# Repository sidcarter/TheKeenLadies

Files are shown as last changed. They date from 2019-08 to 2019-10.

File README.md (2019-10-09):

# Acheron TKL-SM-S-ATM32U4-MX-TH-WI (Codename "TheKeenLadies")

Acheron Logo

See [this page](https://gondolindrim.github.io/AcheronDocs/keenladies/intro.html) for the TheKeenLadies documentation.

## Supported layouts

Click [this link](http://www.keyboard-layout-editor.com/#/gists/6fcb43072b2efaa6a5129e3db566da86) for the KLE file for the TheKeenLadies PCB.

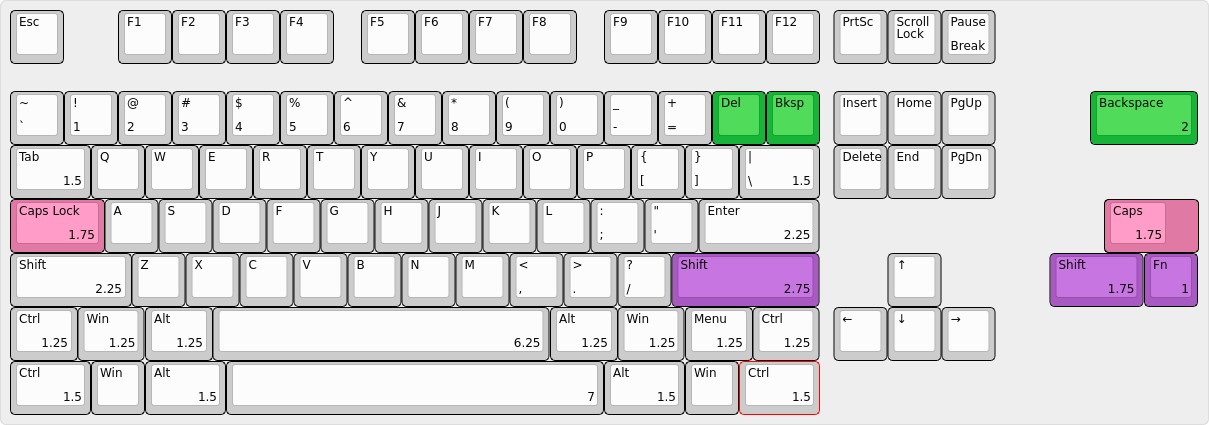
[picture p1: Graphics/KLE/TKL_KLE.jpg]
TKL layouts


## Renders

Click at the images to zoom in.

Renders generated by the [tracespace.io](https://tracespace.io/view/) site.

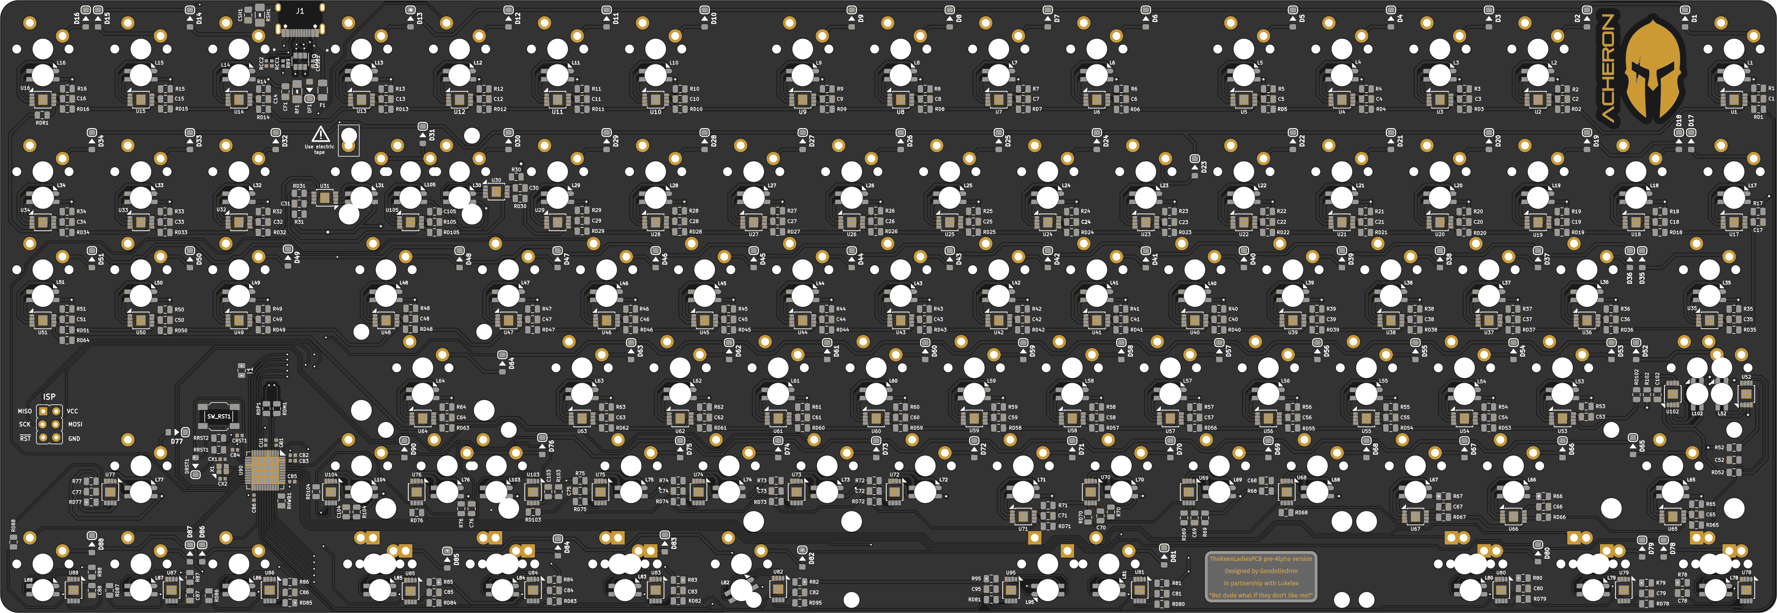
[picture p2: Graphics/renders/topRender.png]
TKL Top Render


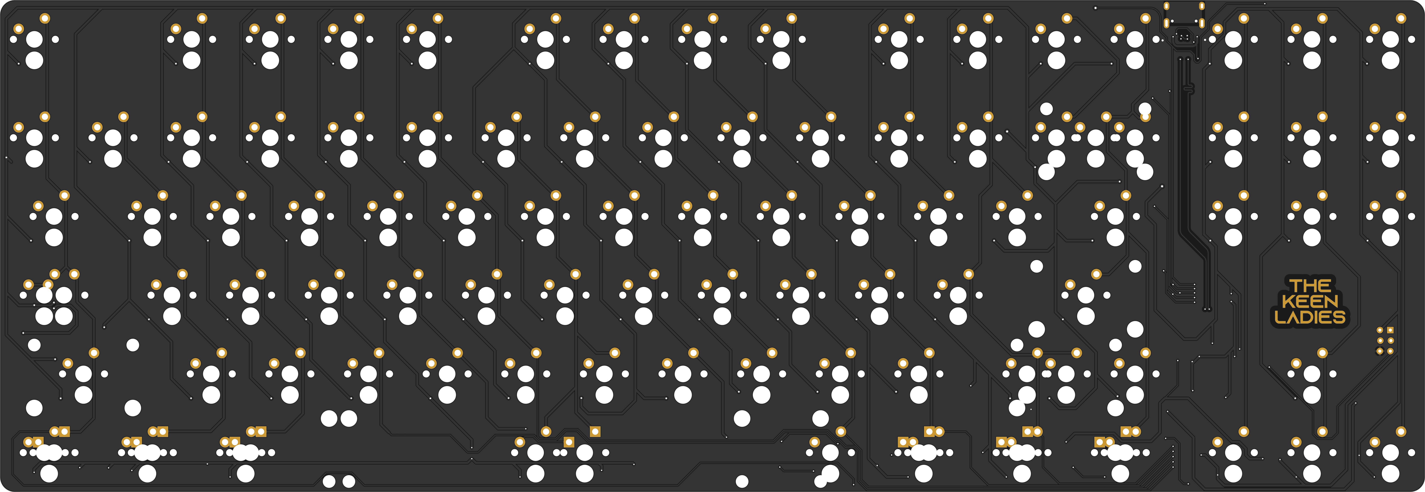
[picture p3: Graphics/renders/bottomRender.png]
TKL Bottom Render


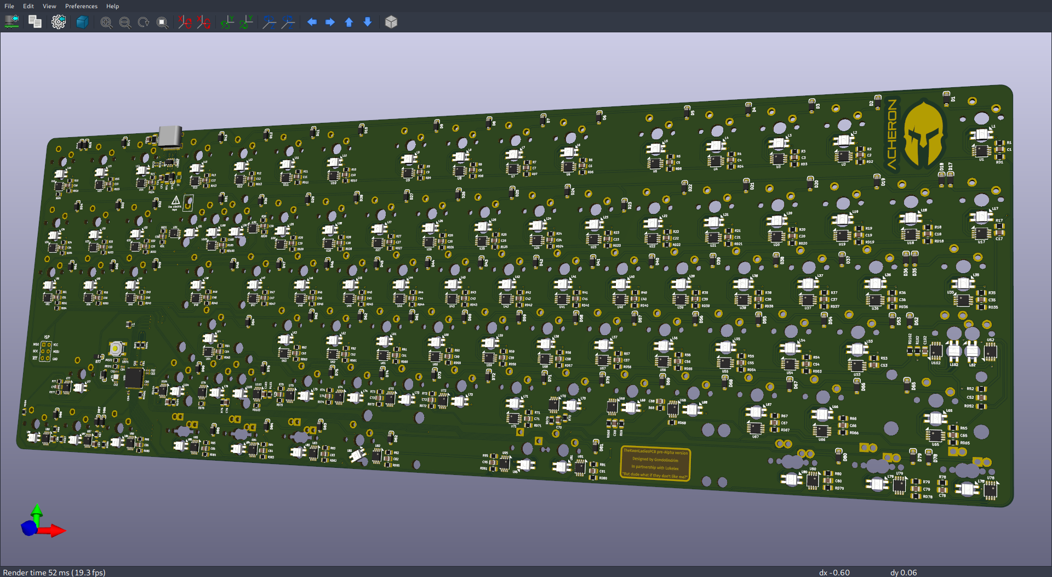
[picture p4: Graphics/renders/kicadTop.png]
TKL KiCad Top Render


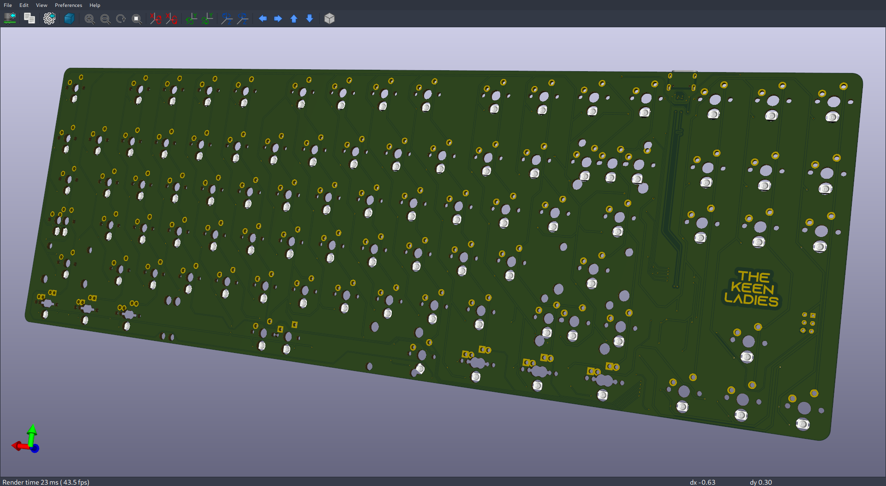
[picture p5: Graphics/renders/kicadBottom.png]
TKL KiCad Bottom Render


## Copyright notice

This project is released under the Acheron Open-Hardware License V1.1. For the license, please refer to the LICENCE.md file.

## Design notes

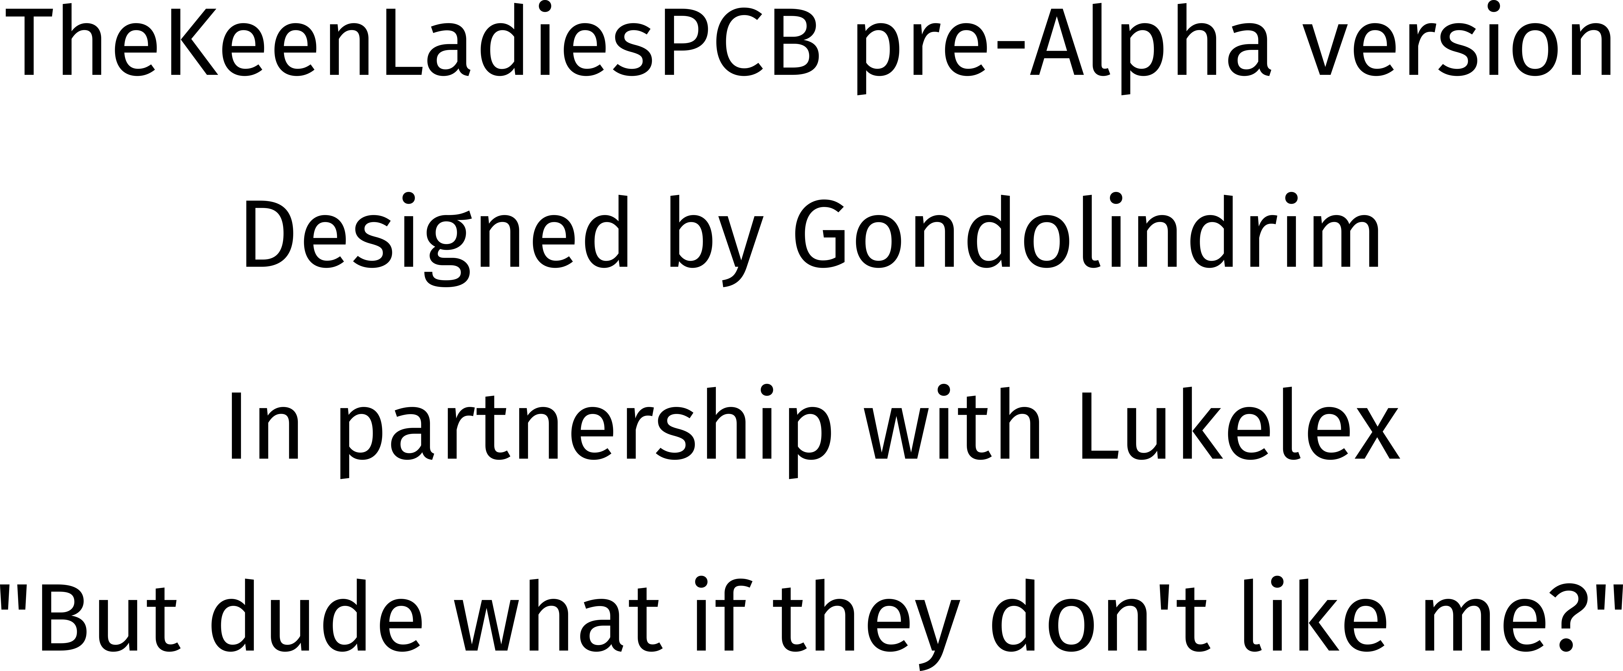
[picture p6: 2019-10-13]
Graphics/label/TKL_label.png

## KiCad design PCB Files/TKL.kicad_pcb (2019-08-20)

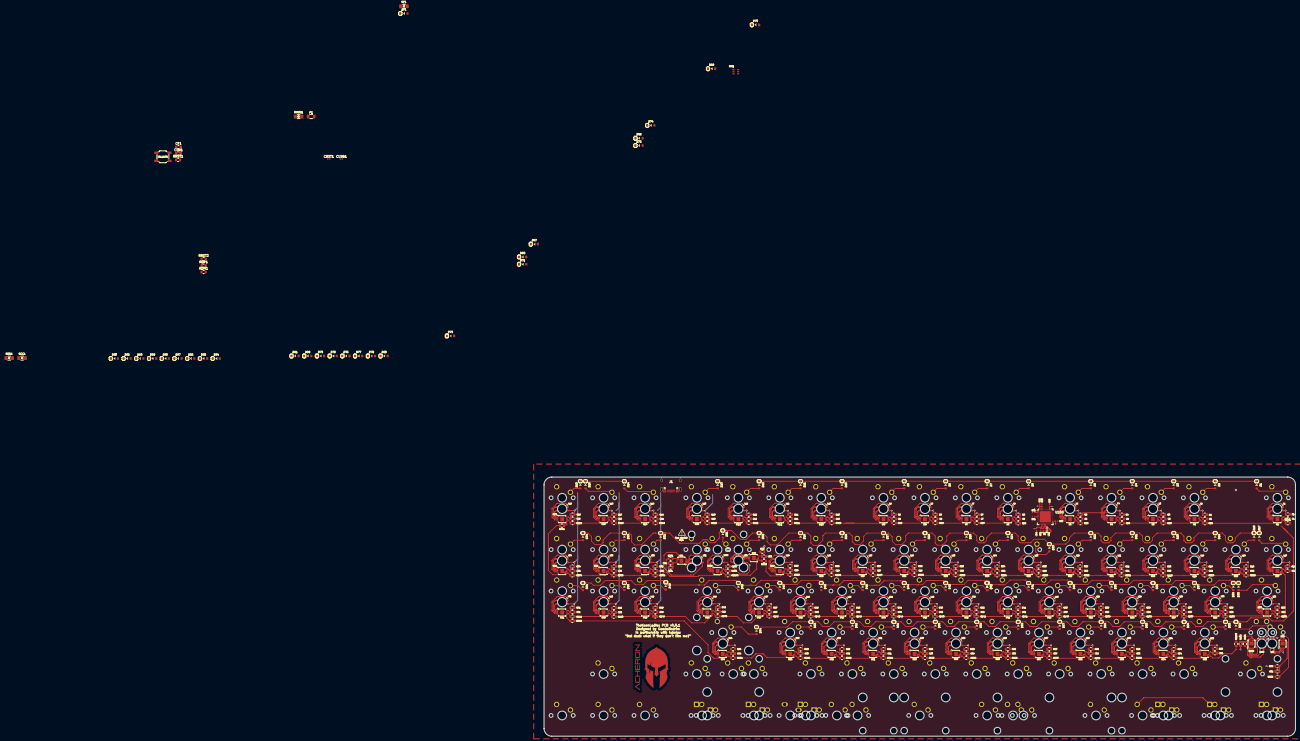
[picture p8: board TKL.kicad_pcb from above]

Board: 2 copper layers, 345.3 x 119.1 mm, 557 parts (1 on the bottom side), 527 nets.

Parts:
C1, C2, C3, C4, C5, C6, C7, C8, C9, C10, C11, C12, C13, C14, C15, C16, C17, C18, C19, C20, C21, C22, C23, C24, C25, C26, C27, C28, C29, C30, C31, C32, C33, C34, C35, C36, C37, C38, C39, C40, C41, C42, C43, C44, C45, C46, C47, C48, C49, C50, C51, C52, C53, C54, C55, C56, C57, C58, C59, C60, C61, C62, C63, C64, C102, C105: 100nF; C_0805_2012Metric
CB1: 1uF; C_0402_1005Metric
CB2, CB3, CB4, CB5, CB6: 100nF; C_0402_1005Metric
CF1: 1u; C_0805_2012Metric_Pad1.15x1.40mm_HandSolder
CRST1: 100nF; C_0402_1005Metric
CSH1: 100nF; C_0805_2012Metric_Pad1.15x1.40mm_HandSolder
CU1: 1uF; C_0402_1005Metric
CUSB1: 100nF; C_0402_1005Metric
CX1, CX2: 8.2pF; C_0402_1005Metric
D1, D2, D3, D4, D5, D6, D7, D8, D9, D10, D11, D12, D13, D14, D15, D16, D17, D18, D19, D20, D21, D22, D23, D24, D25, D26, D27, D28, D29, D30, D31, D32, D33, D34, D35, D36, D37, D38, D39, D40, D41, D42, D42#2, D43, D44, D45, D46, D47, D48, D49, D50, D51, D52, D53, D54, D55, D56, D57, D58, D59, D60, D61, D62, D63, D64, D65, D66, D67, D68, D69, D70, D71, D72, D73, D74, D75, D76, D77, D78, D79, D80, D81, D82, D83, D84, D85, D86, D87, D88, D89, D90: 1N4148; D_SOD-123
DF1: RB060M-60TR; D_SOD-123
F1: Polyfuse; Fuse_1206_3216Metric
G1: TKL Logo; TKL_Logo_11x18mm_Plated
G2: Acheron Short Logo Plated; acheronShort_15.2x21mm_Plated
G3: Warning sign; warning_sign_3.6x3.2mm
J1: USB_C; TYPE-C-31-M-12
L1, L2, L3, L4, L5, L6, L7, L8, L9, L10, L11, L12, L13, L14, L15, L16, L17, L18, L19, L20, L21, L22, L23, L24, L25, L26, L27, L28, L29, L30, L31, L32, L33, L34, L35, L36, L37, L38, L39, L40, L41, L42, L43, L44, L45, L46, L47, L48, L49, L50, L51, L52, L53, L54, L55, L56, L57, L58, L59, L60, L61, L62, L63, L64, L102, L105: LED_BGRA; LED_RGB_SMD_6028_2.8x3.5mm_Round
R1, R2, R3, R4, R5, R6, R7, R8, R9, R10, R11, R12, R13, R14, R15, R16, R17, R18, R19, R20, R21, R22, R23, R24, R25, R26, R27, R28, R29, R30, R31, R32, R33, R34, R35, R36, R37, R38, R39, R40, R41, R42, R43, R44, R45, R46, R47, R48, R49, R50, R51, R52, R53, R54, R55, R56, R57, R58, R59, R60, R61, R62, R63, R64, R102, R105: 100R; R_0805_2012Metric
RCC1: 5.1k; R_SMD_1026
RD1, RD2, RD3, RD4, RD5, RD6, RD7, RD8, RD9, RD10, RD11, RD12, RD13, RD14, RD15, RD16, RD18, RD19, RD20, RD21, RD22, RD23, RD24, RD25, RD26, RD27, RD28, RD29, RD30, RD31, RD32, RD33, RD34, RD35, RD36, RD37, RD38, RD39, RD40, RD41, RD42, RD43, RD44, RD45, RD46, RD47, RD48, RD49, RD50, RD51, RD52, RD54, RD55, RD56, RD57, RD58, RD59, RD60, RD61, RD62, RD63, RD64, RD102, RD105: 33R; R_0805_2012Metric
RDM1: 22; R_0805_2012Metric
RDP1: 22; R_0805_2012Metric
RDR1, RDR2: 33R; R_0805_2012Metric
RF1: 10k; R_SMD_1026
RHWB1: 1k; R_SMD_1026
RRST1: 4.7k; R_0805_2012Metric
RRST2: 330R; R_0805_2012Metric
RSH1: 1M; R_SMD_1026
SW1: ESC; MX100
SW2: F1; MX100
SW3: F2; MX100
SW4: F3; MX100
SW5: F4; MX100
SW6: F5; MX100
SW7: F6; MX100
SW8: F7; MX100
SW9: F8; MX100
SW10: F9; MX100
SW11: F10; MX100
SW12: F11; MX100
SW13: F12; MX100
SW14: PRTSC; MX100
SW15: SCRLCK; MX100
SW16: PAUSE; MX100
SW17: GRV; MX100
SW18: 1; MX100
SW19: 2; MX100
SW20: 3; MX100
SW21: 4; MX100
SW22: 5; MX100
SW23: 6; MX100
SW24: 7; MX100
SW25: 8; MX100
SW26: 9; MX100
SW27: 0; MX100
SW28: HIFEN; MX100
SW29: PLUS; MX100
SW30: BCKSLSH; MX100
SW31, SW49: DEL; MX100
SW32: INS; MX100
SW33: HOME; MX100
SW34: PGUP; MX100
SW35: TAB; MX150
SW36: Q; MX100
SW37: W; MX100
SW38: E; MX100
SW39: R; MX100
SW40: T; MX100
SW41: Y; MX100
SW42: U; MX100
SW43: I; MX100
SW44: O; MX100
SW45: P; MX100
SW46: LBRACES; MX100
SW47: RBRACES; MX100
SW48: BKSP_150; MX150
SW50: END; MX100
SW51: PGDN; MX100
SW52: CAPS; MX175
SW53: A; MX100
SW54: S; MX100
SW55: D; MX100
SW56: F; MX100
SW57: G; MX100
SW58: H; MX100
SW59: J; MX100
SW60: K; MX100
SW61: L; MX100
SW62: :; MX100
SW63: QUOTE; MX100
SW64: ENTER; MX225
SW65: LSHFT; MX225
SW66: Z; MX100
SW67: X; MX100
SW68: C; MX100
SW69: V; MX100
SW70: B; MX100
SW71: N; MX100
SW72: M; MX100
SW73: <,; MX100
SW74: .>; MX100
SW75: /; MX100
SW76: RSHFT_275; MX275
SW77: UP; MX100
SW78: LCTRL_B1; MX125
SW79: LGUI_B1; MX125
SW80: LALT_B1; MX125
SW81: SPACE_B1; MX625R
SW82: RALT_B1; MX125
SW83: RGUI_B1; MX125
SW84: MENU_R1; MX125
SW85: RCTRL_R1; MX125
SW86: LEFT; MX100
SW87: DOWN; MX100
SW88: RIGHT; MX100
SW89: LCTRL_B2; MX150
SW90: LGUI_B2; MX100
SW91: LALT_B3; MX100
SW92: LALT_B2; MX150
SW93: LGUI_B3; MX125
SW94: LSPC_R3; MX225R
SW95: SPACE_B2; MX700R
SW96: RSPC_B3; MX275R
SW97: RGUI_R3; MX125
SW98: RALT_B2; MX150
SW99: RALT_R3; MX100
SW100: RGUI_R2; MX100
SW101: RCTRL_R2; MX150
SW102: STEPPED_CAPS; MX125
SW103: RSHFT_175; MX175
SW104: Fn; MX100
SW105: BKSP_2U; MX200
SW_RST1: SW_Push; smdPushBtn
U1, U2, U3, U4, U5, U6, U7, U8, U9, U10, U11, U12, U13, U14, U15, U16, U17, U18, U19, U20, U21, U22, U23, U24, U25, U26, U27, U28, U29, U30, U31, U32, U33, U34, U35, U36, U37, U38, U39, U40, U41, U42, U43, U44, U45, U46, U47, U48, U49, U50, U51, U52, U53, U54, U55, U56, U57, U58, U59, U60, U61, U62, U63, U64, U102, U105: WS2811M; MSOP-8-1EP_3x3mm_P0.65mm_EP1.68x1.88mm
U200: ATMEGA32U4; QFN-44-1EP_7x7mm_P0.5mm_EP5.2x5.2mm
U201: USBLC6-2SC6; SOT-23-6
X1: 16MHz; Crystal_SMD_2016-4Pin_2.0x1.6mm

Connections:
5V: CB1.2, CB2.1, CB3.2, CB4.2, CB5.1, CB6.1, CF1.2, DF1.1, F1.1, L1.4, L2.4, L3.4, L4.4, L5.4, L6.4, L7.4, L8.4, L9.4, L10.4, L11.4, L12.4, L13.4, L14.4, L15.4, L16.4, L17.4, L18.4, L19.4, L20.4, L21.4, L22.4, L23.4, L24.4, L25.4, L26.4, L27.4, L28.4, L29.4, L30.4, L31.4, L32.4, L33.4, L34.4, L35.4, L36.4, L37.4, L38.4, L39.4, L40.4, L41.4, L42.4, L43.4, L44.4, L45.4, L46.4, L47.4, L48.4, L49.4, L50.4, L51.4, L52.4, L53.4, L54.4, L55.4, L56.4, L57.4, L58.4, L59.4, L60.4, L61.4, L62.4, L63.4, L64.4, L102.4, L105.4, R1.1, R2.1, R3.1, R4.1, R5.1, R6.1, R7.1, R8.1, R9.1, R10.1, R11.1, R12.1, R13.1, R14.1, R15.1, R16.1, R17.1, R18.1, R19.1, R20.1, R21.1, R22.1, R23.1, R24.1, R25.1, R26.1, R27.1, R28.1, R29.1, R30.1, R31.1, R32.1, R33.1, R34.1, R35.1, R36.1, R37.1, R38.1, R39.1, R40.1, R41.1, R42.1, R43.1, R44.1, R45.1, R46.1, R47.1, R48.1, R49.1, R50.1, R51.1, R52.1, R53.1, R54.1, R55.1, R56.1, R57.1, R58.1, R59.1, R60.1, R61.1, R62.1, R63.1, R64.1, R102.1, R105.1, RF1.2, RRST1.2, U200.2, U200.7, U200.14, U200.24, U200.35, U200.42, U200.44
/RST: CRST1.2, RRST1.1, RRST2.2, U200.13
/SHIELD: CSH1.1, J1.S, RSH1.2
/XTAL1: CX2.1, U200.17, X1.1
/XTAL2: CX1.1, U200.16, X1.3
Col1: SW1.1, SW17.1, SW35.1, SW52.1, SW65.1, SW78.1, SW89.1, SW102.1
Col2: SW18.1, SW36.1, SW53.1, SW66.1, SW79.1, SW90.1, SW91.1
Col3: SW2.1, SW19.1, SW37.1, SW54.1, SW67.1, SW80.1, SW92.1, SW93.1
Col4: SW3.1, SW20.1, SW38.1, SW55.1, SW68.1
Col5: SW4.1, SW21.1, SW39.1, SW56.1, SW69.1, SW94.1
Col6: SW5.1, SW22.1, SW40.1, SW57.1, SW70.1
Col7: SW23.1, SW41.1, SW58.1, SW71.1, SW81.1, SW95.1, SW96.1
Col8: SW6.1, SW24.1, SW42.1, SW59.1, SW72.1
Col9: SW7.1, SW25.1, SW43.1, SW60.1, SW73.1
Col10: SW8.1, SW26.1, SW44.1, SW61.1, SW74.1, SW82.1, SW97.1
Col11: SW9.1, SW27.1, SW45.1, SW62.1, SW75.1, SW83.1, SW98.1, SW99.1
Col12: SW10.1, SW28.1, SW46.1
Col13: SW11.1, SW29.1, SW47.1, SW63.1, SW76.1, SW84.1, SW100.1, SW103.1
Col14: SW12.1, SW30.1
Col15: SW13.1, SW31.1, SW48.1, SW64.1, SW85.1, SW101.1, SW104.1, SW105.1
Col16: SW14.1, SW32.1, SW49.1, SW86.1
Col17: SW15.1, SW33.1, SW50.1, SW77.1, SW87.1
Col18: SW16.1, SW34.1, SW51.1, SW88.1
DBusN: J1.A7, J1.B7, U201.1
DBusP: J1.A6, J1.B6, U201.3
DN: RDM1.2, U200.3
DP: RDP1.1, U200.4
GND: C1.2, C2.2, C3.2, C4.2, C5.2, C6.2, C7.2, C8.2, C9.2, C10.2, C11.2, C12.2, C13.2, C14.2, C15.2, C16.2, C17.2, C18.2, C19.2, C20.2, C21.2, C22.2, C23.2, C24.2, C25.2, C26.2, C27.2, C28.2, C29.2, C30.2, C31.2, C32.2, C33.2, C34.2, C35.2, C36.2, C37.2, C38.2, C39.2, C40.2, C41.2, C42.2, C43.2, C44.2, C45.2, C46.2, C47.2, C48.2, C49.2, C50.2, C51.2, C52.2, C53.2, C54.2, C55.2, C56.2, C57.2, C58.2, C59.2, C60.2, C61.2, C62.2, C63.2, C64.2, C102.2, C105.2, CB1.1, CB2.2, CB3.1, CB4.1, CB5.2, CB6.2, CF1.1, CRST1.1, CSH1.2, CU1.2, CUSB1.2, CX1.2, CX2.2, DF1.2, J1.A1, J1.B1, RCC1.2, RF1.1, RHWB1.1, RSH1.1, SW_RST1.1, U1.4, U1.9, U2.4, U2.9, U3.4, U3.9, U4.4, U4.9, U5.4, U5.9, U6.4, U6.9, U7.4, U7.9, U8.4, U8.9, U9.4, U9.9, U10.4, U10.9, U11.4, U11.9, U12.4, U12.9, U13.4, U13.9, U14.4, U14.9, U15.4, U15.9, U16.4, U16.9, U17.4, U17.9, U18.4, U18.9, U19.4, U19.9, U20.4, U20.9, U21.4, U21.9, U22.4, U22.9, U23.4, U23.9, U24.4, U24.9, U25.4, U25.9, U26.4, U26.9, U27.4, U27.9, U28.4, U28.9, U29.4, U29.9, U30.4, U30.9, U31.4, U31.9, U32.4, U32.9, U33.4, U33.9, U34.4, U34.9, U35.4, U35.9, U36.4, U36.9, U37.4, U37.9, U38.4, U38.9, U39.4, U39.9, U40.4, U40.9, U41.4, U41.9, U42.4, U42.9, U43.4, U43.9, U44.4, U44.9, U45.4, U45.9, U46.4, U46.9, U47.4, U47.9, U48.4, U48.9, U49.4, U49.9, U50.4, U50.9, U51.4, U51.9, U52.4, U52.9, U53.4, U53.9, U54.4, U54.9, U55.4, U55.9, U56.4, U56.9, U57.4, U57.9, U58.4, U58.9, U59.4, U59.9, U60.4, U60.9, U61.4, U61.9, U62.4, U62.9, U63.4, U63.9, U64.4, U64.9, U102.4, U102.9, U105.4, U105.9, U200.5, U200.15, U200.23, U200.34, U200.43, U201.2, X1.2, X1.4
L1: D78.2, SW78.2, SW89.2
L2: D79.2, SW79.2, SW90.2, SW91.2
L3: D80.2, SW80.2, SW92.2, SW93.2
L4: D81.2, SW81.2, SW95.2, SW96.2
L5: D82.2, SW82.2, SW97.2
L6: D83.2, SW83.2, SW98.2, SW99.2
L7: D84.2, SW84.2, SW100.2
L8: D85.2, SW85.2, SW101.2
unnamed: C1.1, R1.2, U1.8
unnamed: C2.1, R2.2, U2.8
unnamed: C3.1, R3.2, U3.8
unnamed: C4.1, R4.2, U4.8
unnamed: C5.1, R5.2, U5.8
unnamed: C6.1, R6.2, U6.8
unnamed: C7.1, R7.2, U7.8
unnamed: C8.1, R8.2, U8.8
unnamed: C9.1, R9.2, U9.8
unnamed: C10.1, R10.2, U10.8
unnamed: C11.1, R11.2, U11.8
unnamed: C12.1, R12.2, U12.8
unnamed: C13.1, R13.2, U13.8
unnamed: C14.1, R14.2, U14.8
unnamed: C15.1, R15.2, U15.8
unnamed: C16.1, R16.2, U16.8
unnamed: C17.1, R17.2, U17.8
unnamed: C18.1, R18.2, U18.8
unnamed: C19.1, R19.2, U19.8
unnamed: C20.1, R20.2, U20.8
unnamed: C21.1, R21.2, U21.8
unnamed: C22.1, R22.2, U22.8
unnamed: C23.1, R23.2, U23.8
unnamed: C24.1, R24.2, U24.8
unnamed: C25.1, R25.2, U25.8
unnamed: C26.1, R26.2, U26.8
unnamed: C27.1, R27.2, U27.8
unnamed: C28.1, R28.2, U28.8
unnamed: C29.1, R29.2, U29.8
unnamed: C30.1, R30.2, U30.8
unnamed: C31.1, R31.2, U31.8
unnamed: C32.1, R32.2, U32.8
unnamed: C33.1, R33.2, U33.8
unnamed: C34.1, R34.2, U34.8
unnamed: C35.1, R35.2, U35.8
unnamed: C36.1, R36.2, U36.8
unnamed: C37.1, R37.2, U37.8
unnamed: C38.1, R38.2, U38.8
unnamed: C39.1, R39.2, U39.8
unnamed: C40.1, R40.2, U40.8
unnamed: C41.1, R41.2, U41.8
unnamed: C42.1, R42.2, U42.8
unnamed: C43.1, R43.2, U43.8
unnamed: C44.1, R44.2, U44.8
unnamed: C45.1, R45.2, U45.8
unnamed: C46.1, R46.2, U46.8
unnamed: C47.1, R47.2, U47.8
unnamed: C48.1, R48.2, U48.8
unnamed: C49.1, R49.2, U49.8
unnamed: C50.1, R50.2, U50.8
unnamed: C51.1, R51.2, U51.8
unnamed: C52.1, R52.2, U52.8
unnamed: C53.1, R53.2, U53.8
unnamed: C54.1, R54.2, U54.8
unnamed: C55.1, R55.2, U55.8
unnamed: C56.1, R56.2, U56.8
unnamed: C57.1, R57.2, U57.8
unnamed: C58.1, R58.2, U58.8
unnamed: C59.1, R59.2, U59.8
unnamed: C60.1, R60.2, U60.8
unnamed: C61.1, R61.2, U61.8
unnamed: C62.1, R62.2, U62.8
unnamed: C63.1, R63.2, U63.8
unnamed: C64.1, R64.2, U64.8
unnamed: C102.1, R102.2, U102.8
unnamed: C105.1, R105.2, U105.8
unnamed: CU1.1, U200.6
unnamed: D1.2, SW1.2
unnamed: D2.2, SW2.2
unnamed: D3.2, SW3.2
unnamed: D4.2, SW4.2
unnamed: D5.2, SW5.2
unnamed: D6.2, SW6.2
unnamed: D7.2, SW7.2
unnamed: D8.2, SW8.2
unnamed: D9.2, SW9.2
unnamed: D10.2, SW10.2
unnamed: D11.2, SW11.2
unnamed: D12.2, SW12.2
unnamed: D13.2, SW13.2
unnamed: D14.2, SW14.2
unnamed: D15.2, SW15.2
unnamed: D16.2, SW16.2
unnamed: D17.2, SW17.2
unnamed: D18.2, SW18.2
unnamed: D19.2, SW19.2
unnamed: D20.2, SW20.2
unnamed: D21.2, SW21.2
unnamed: D22.2, SW22.2
unnamed: D23.2, SW23.2
unnamed: D24.2, SW24.2
unnamed: D25.2, SW25.2
unnamed: D26.2, SW26.2
unnamed: D27.2, SW27.2
unnamed: D28.2, SW28.2
unnamed: D29.2, SW29.2
unnamed: D30.2, SW30.2
unnamed: D31.2, SW31.2, SW105.2
unnamed: D32.2, SW32.2
unnamed: D33.2, SW33.2
unnamed: D34.2, SW34.2
unnamed: D35.2, SW35.2
unnamed: D36.2, SW36.2
unnamed: D37.2, SW37.2
unnamed: D38.2, SW38.2
unnamed: D39.2, SW39.2
unnamed: D40.2, SW40.2
unnamed: D41.2, SW41.2
unnamed: D42.2, D42#2.2, SW42.2
unnamed: D43.2, SW43.2
unnamed: D44.2, SW44.2
unnamed: D45.2, SW45.2
unnamed: D46.2, SW46.2
unnamed: D47.2, SW47.2
unnamed: D48.2, SW48.2
unnamed: D49.2, SW49.2
unnamed: D50.2, SW50.2
unnamed: D51.2, SW51.2
unnamed: D52.2, SW52.2, SW102.2
unnamed: D53.2, SW53.2
unnamed: D54.2, SW54.2
unnamed: D55.2, SW55.2
unnamed: D56.2, SW56.2
unnamed: D57.2, SW57.2
unnamed: D58.2, SW58.2
unnamed: D59.2, SW59.2
unnamed: D60.2, SW60.2
unnamed: D61.2, SW61.2
unnamed: D62.2, SW62.2
unnamed: D63.2, SW63.2
unnamed: D64.2, SW64.2
unnamed: D65.2, SW65.2
unnamed: D66.2, SW66.2
unnamed: D67.2, SW67.2
unnamed: D68.2, SW68.2
unnamed: D69.2, SW69.2
unnamed: D70.2, SW70.2
unnamed: D71.2, SW71.2
unnamed: D72.2, SW72.2
unnamed: D73.2, SW73.2
unnamed: D74.2, SW74.2
unnamed: D75.2, SW75.2
unnamed: D76.2, SW76.2, SW103.2
unnamed: D77.2, SW77.2
unnamed: D86.2, SW86.2
unnamed: D87.2, SW87.2
unnamed: D88.2, SW88.2
unnamed: D89.2, SW94.2
unnamed: D90.2, SW104.2
unnamed: J1.A5, J1.B5, RCC1.1
unnamed: L1.1, U1.3
unnamed: L1.2, U1.2
unnamed: L1.3, U1.1
unnamed: L2.1, U2.3
unnamed: L2.2, U2.2
unnamed: L2.3, U2.1
unnamed: L3.1, U3.3
unnamed: L3.2, U3.2
unnamed: L3.3, U3.1
unnamed: L4.1, U4.3
unnamed: L4.2, U4.2
unnamed: L4.3, U4.1
unnamed: L5.1, U5.3
unnamed: L5.2, U5.2
unnamed: L5.3, U5.1
unnamed: L6.1, U6.3
unnamed: L6.2, U6.2
unnamed: L6.3, U6.1
unnamed: L7.1, U7.3
unnamed: L7.2, U7.2
unnamed: L7.3, U7.1
unnamed: L8.1, U8.3
unnamed: L8.2, U8.2
unnamed: L8.3, U8.1
unnamed: L9.1, U9.3
unnamed: L9.2, U9.2
unnamed: L9.3, U9.1
unnamed: L10.1, U10.3
unnamed: L10.2, U10.2
unnamed: L10.3, U10.1
unnamed: L11.1, U11.3
unnamed: L11.2, U11.2
unnamed: L11.3, U11.1
unnamed: L12.1, U12.3
unnamed: L12.2, U12.2
unnamed: L12.3, U12.1
unnamed: L13.1, U13.3
unnamed: L13.2, U13.2
unnamed: L13.3, U13.1
unnamed: L14.1, U14.3
unnamed: L14.2, U14.2
unnamed: L14.3, U14.1
unnamed: L15.1, U15.3
unnamed: L15.2, U15.2
unnamed: L15.3, U15.1
unnamed: L16.1, U16.3
unnamed: L16.2, U16.2
unnamed: L16.3, U16.1
unnamed: L17.1, U17.3
unnamed: L17.2, U17.2
unnamed: L17.3, U17.1
unnamed: L18.1, U18.3
unnamed: L18.2, U18.2
unnamed: L18.3, U18.1
unnamed: L19.1, U19.3
unnamed: L19.2, U19.2
unnamed: L19.3, U19.1
unnamed: L20.1, U20.3
unnamed: L20.2, U20.2
unnamed: L20.3, U20.1
unnamed: L21.1, U21.3
unnamed: L21.2, U21.2
unnamed: L21.3, U21.1
unnamed: L22.1, U22.3
unnamed: L22.2, U22.2
unnamed: L22.3, U22.1
unnamed: L23.1, U23.3
unnamed: L23.2, U23.2
unnamed: L23.3, U23.1
unnamed: L24.1, U24.3
unnamed: L24.2, U24.2
unnamed: L24.3, U24.1
unnamed: L25.1, U25.3
unnamed: L25.2, U25.2
unnamed: L25.3, U25.1
unnamed: L26.1, U26.3
unnamed: L26.2, U26.2
unnamed: L26.3, U26.1
unnamed: L27.1, U27.3
unnamed: L27.2, U27.2
unnamed: L27.3, U27.1
unnamed: L28.1, U28.3
unnamed: L28.2, U28.2
unnamed: L28.3, U28.1
unnamed: L29.1, U29.3
unnamed: L29.2, U29.2
unnamed: L29.3, U29.1
unnamed: L30.1, U30.3
unnamed: L30.2, U30.2
unnamed: L30.3, U30.1
unnamed: L31.1, U31.3
unnamed: L31.2, U31.2
unnamed: L31.3, U31.1
unnamed: L32.1, U32.3
unnamed: L32.2, U32.2
unnamed: L32.3, U32.1
unnamed: L33.1, U33.3
unnamed: L33.2, U33.2
unnamed: L33.3, U33.1
unnamed: L34.1, U34.3
unnamed: L34.2, U34.2
unnamed: L34.3, U34.1
unnamed: L35.1, U35.3
unnamed: L35.2, U35.2
unnamed: L35.3, U35.1
unnamed: L36.1, U36.3
unnamed: L36.2, U36.2
unnamed: L36.3, U36.1
unnamed: L37.1, U37.3
unnamed: L37.2, U37.2
unnamed: L37.3, U37.1
unnamed: L38.1, U38.3
unnamed: L38.2, U38.2
unnamed: L38.3, U38.1
unnamed: L39.1, U39.3
unnamed: L39.2, U39.2
unnamed: L39.3, U39.1
unnamed: L40.1, U40.3
unnamed: L40.2, U40.2
unnamed: L40.3, U40.1
unnamed: L41.1, U41.3
unnamed: L41.2, U41.2
unnamed: L41.3, U41.1
unnamed: L42.1, U42.3
unnamed: L42.2, U42.2
unnamed: L42.3, U42.1
unnamed: L43.1, U43.3
unnamed: L43.2, U43.2
unnamed: L43.3, U43.1
unnamed: L44.1, U44.3
unnamed: L44.2, U44.2
unnamed: L44.3, U44.1
unnamed: L45.1, U45.3
unnamed: L45.2, U45.2
unnamed: L45.3, U45.1
unnamed: L46.1, U46.3
unnamed: L46.2, U46.2
unnamed: L46.3, U46.1
unnamed: L47.1, U47.3
unnamed: L47.2, U47.2
unnamed: L47.3, U47.1
unnamed: L48.1, U48.3
unnamed: L48.2, U48.2
unnamed: L48.3, U48.1
unnamed: L49.1, U49.3
unnamed: L49.2, U49.2
unnamed: L49.3, U49.1
unnamed: L50.1, U50.3
unnamed: L50.2, U50.2
unnamed: L50.3, U50.1
unnamed: L51.1, U51.3
unnamed: L51.2, U51.2
unnamed: L51.3, U51.1
unnamed: L52.1, U52.3
unnamed: L52.2, U52.2
unnamed: L52.3, U52.1
unnamed: L53.1, U53.3
unnamed: L53.2, U53.2
unnamed: L53.3, U53.1
unnamed: L54.1, U54.3
unnamed: L54.2, U54.2
unnamed: L54.3, U54.1
unnamed: L55.1, U55.3
unnamed: L55.2, U55.2
unnamed: L55.3, U55.1
unnamed: L56.1, U56.3
unnamed: L56.2, U56.2
unnamed: L56.3, U56.1
unnamed: L57.1, U57.3
unnamed: L57.2, U57.2
unnamed: L57.3, U57.1
unnamed: L58.1, U58.3
unnamed: L58.2, U58.2
unnamed: L58.3, U58.1
unnamed: L59.1, U59.3
unnamed: L59.2, U59.2
unnamed: L59.3, U59.1
unnamed: L60.1, U60.3
unnamed: L60.2, U60.2
unnamed: L60.3, U60.1
unnamed: L61.1, U61.3
unnamed: L61.2, U61.2
unnamed: L61.3, U61.1
unnamed: L62.1, U62.3
unnamed: L62.2, U62.2
unnamed: L62.3, U62.1
unnamed: L63.1, U63.3
unnamed: L63.2, U63.2
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

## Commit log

2019-08-11 Placed switches
    [TKL.kicad_pcb, TKL.sch]
2019-08-12 Positioned switches
    - The switches were positioned onto the PCB and the first WS2811 modules and RGB LEDs also were added. As of this commit, the edge layer drawings are a simple guideline and won't reflect the final dimensions or format.
    - Added plated logo
    [TKL.kicad_pcb, TKL.sch]
2019-08-12 Routed RGB components and reorganized columns
    - The WS2811M datasheet states that every unit must have two resistors and a capacitor around it; one resistor (33R) for the data lines and a resistor and capacitor (RC filter, 100R and 100nF) for bypass and spike prevention. These components were added.
    - Laid the RGB components for some switches. Following the addition of the extra components for the RGB controllers, the RGB components (controller, resistors and capacitor and the LED) were added to a fourth of the total switches. The trace pattern was made to be repeatable through the whole PCB, in order to make a somewhat default trace pattern.
    - The bigger 15x21mm short Acheron logo was added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
    [TKL.kicad_pcb, TKL.sch]
2019-08-13 Further routing and placement
    [TKL.kicad_pcb, TKL.sch]
2019-08-13 Placed and routed second row
    [TKL.kicad_pcb, TKL.sch]
2019-08-15 Added third RGB row to schematic
    [TKL.kicad_pcb, TKL.sch]
2019-08-15 Placed RGB components L35-L51 to third row on PCB
    [TKL.kicad_pcb]
2019-08-15 Fixed RGB and controller labels
    [TKL.kicad_pcb]
2019-08-16 Routed 3rd row and columns
    - The RGB 3rd row was routed; all components were added, their labels fixed and cleaned.
    - All columns were routed. Some were reassigned for better fitting. It may be that I'll redo some columns in the near future as the routing does not look clean, specially in the bottom row;
    - A warning sign was added to show that, when using a screw-in stab on the 2U backspace, there should be an electric tape preventing the screw from short-circuiting to the column pad.
    [TKL.kicad_pcb, TKL.sch]
2019-08-16 Added TGB fourth row to schematic
    [TKL.sch]
2019-08-16 Placed RGB LEDs and controllers of 4th row
    [TKL.kicad_pcb, TKL.sch]
2019-08-16 Routed first 4 RGB LEDs
    [TKL.kicad_pcb, TKL.sch]
2019-08-17 Routed SW55 RGB
    [TKL.kicad_pcb]
2019-08-17 Routed SW56 RGB LED
    [TKL.kicad_pcb]
2019-08-17 Routed SW57 RGB LED
    [TKL.kicad_pcb]
2019-08-17 Routed SW58 RGB LED
    [TKL.kicad_pcb]
2019-08-17 Routed SW59 RGB LED
    [TKL.kicad_pcb]
2019-08-17 Routed SW60 RGB LED
    [TKL.kicad_pcb]
2019-08-17 Routed SW61 RGB LED
    [TKL.kicad_pcb]
2019-08-17 Routed SW62 RGB LED
    [TKL.kicad_pcb]
2019-08-17 Routed SW63 RGB LED
    [TKL.kicad_pcb]
2019-08-17 Routed SW64 RGB LED
    [TKL.kicad_pcb]
2019-08-17 Fix orientation of RD55, 56 and 57
    [TKL.kicad_pcb]
2019-08-17 Renamed RD52-64 to match controller number
    [TKL.kicad_pcb]
2019-08-17 Route fourth row
    [TKL.kicad_pcb, TKL.sch]
2019-08-20 Add plate DXF, route bypass capacitors
    [TKL.kicad_pcb]
2019-08-20 Add case drawings, redo PCB edges
    - Added case drawings in Eco2.User layer
    - PCB Edges were redone to fit the case.
    [TKL.kicad_pcb]
2019-08-20 Rotuted USB Connector and D+ D-
    [TKL.sch]
2019-08-20 Route connector, pre-route colummns and rows
    - The connector area was routed with the ESD and shield components. This includes USBLC6, fuse and shield discharge net.
    - The columns were routed to almost complete degree. THe were not completely routed because the bottom row may have some changes to its column ordering.
    - Columns and rows were pre-routed. This means that routes from them to the MCU were devised to indicate how they will be and to organize PCB space.
2019-08-20 - Add license and readme, update PCB backup files
    - LICENSE and README were added
    - Backup for schematic and footprint library were also modified
    [TKL.sch]
2019-08-21 Rename RGB 3rd row RD annotation
    - Fixed a small isue where resistors RD in the 3RD row of RGB controllers were misannotated: they were all a number ahead (i.e., where it should be RD(X) was RD(X+1))
    [TKL.sch]
2019-08-21 Add 4th RGB row
    [TKL.sch]
2019-08-21 Anntate 4th RGB LED component row
    [TKL.sch]
2019-08-21 Remove RGB LED 77 second instance
    - There were two instances of RGB LED 77
    [TKL.sch]
2019-08-21 Place 4th row of LEDs
    - The RGB LEDs of 4th row were placed. In order to do this, some traces had to be re-wired, specially the ones that link columns to their MCU pins. RGB WS2811 controllers and their respective compone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
2019-08-21 Experiment with curved traces
    - Some traces were curved
    [TKL.sch]
2019-08-22 Place 4th row RGB WS2811 controllers
    [TKL.sch]
2019-08-22 Route 5V net, columns nets
    - Routed part of the 5V net. Also routed and assgned pins to some columns and rows nets.
    [TKL.sch]
2019-09-01 Organized schematic
    [TKL.sch]
2019-09-01 Further routed 5V trace
2019-09-01 Re-routed some columns for a cleaner routing
    [TKL.sch]
2019-09-01 Routed RGB76
    [TKL.sch]
2019-09-01 Placed last row switches
2019-09-01 Added last row RGB components to schematic
    [TKL.sch]
2019-09-01 Routed SW88 RGB LED
    [TKL.sch]
2019-09-01 Routed SW87 RGB LED
2019-09-01 Placed last row LEDs
    [TKL.sch]
2019-09-30 Update: routed more RGBs, removed split bottom row
    [TKL.sch]
2019-09-30 Update: new RGB LED footprint
    - A new footprint was used for the RGB LEDs, since the last footprint
    was noe fine adjusted and was yielding too many DRC error due to pad
    placement and hole size. See the AcheronLibrary commit 1ad4dd26 for more information.
2019-10-08 Update: Finish routing
    - All tracks were routed
    - There are some extra pins that need to be broken out.
    - Also the serial programming ISP pins need to be broken out.
    - After that is done, run DRC and correct eventual flaws
    [TKL.sch]
2019-10-09 Run DRC, solve issues
    - DRC was run and some issues arose. This means that some tracks needed
    to be re-routed.
    - Almost all columns and rows routed, except for Col12, Col15 and Row6.
    - The ISP JTAG pins were broken out
    - Some silkscreens were re-done for clarification
    - The shield copper fill was further distanced from the GND copper fill
    - A switch that did not correspond to any layout was removed
    - The D+/D- USB differential pair now has a 20mil clearance
    [TKL.sch]
2019-10-09 Route rest of cols and rows
    [TKL.sch]
2019-10-09 Added KiCad renders
2019-10-11 Rename folder 'PCB Files' to 'PCB_Files'
    [TKL.sch]
2019-10-13 Add RCC2, R89
    - RCC2 was added as per USB2.0 compliance;
    - R89 (pullup resistor between USB D+ and USB power) was added as per
    USB2.0 full speed devices compliance.
    [TKL.sch]
2019-10-13 Add choke, reset diode
    - Choke I1 and reset diode DRST1 were added for better reliability
    [TKL.sch]
2019-10-16 Update library, add label
    - Updated the AcheronLibrary, specifically the 6028 RGB LED footprint,
    which is now marked as an SMD component
    - The label was added
    - Renders were updated
    [TKL.sch]
